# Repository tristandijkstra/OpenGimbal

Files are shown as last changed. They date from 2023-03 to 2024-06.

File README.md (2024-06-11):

# OpenGimbal

If you do end up using the platform for research then you can cite us using the details below:

@ARTICLE{10225720, author={Sharma, Suryansh and Dijkstra, Tristan and Prasad, Ranga Venkatesha}, journal={IEEE Sensors Letters}, title={Open Gimbal: A 3 Degrees of Freedom Open Source Sensing and Testing Platform for Nano- and Micro-UAVs}, year={2023}, volume={7}, number={9}, pages={1-4}, doi={10.1109/LSENS.2023.3307121}}



OpenGimbal is a specially designed 3 DoF test bench that caters to the unique requirements of mUAVs and nUAVs. This test bench allows for unrestricted rotational motion, enabling comprehensive experimentation and evaluation of these UAVs. Our approach focuses on simplicity and accessibility. We developed an open-source, 3D printable electro-mechanical  design that emphasizes minimal size and complexity. This design facilitates easy replication and customization, making it widely accessible to researchers and developers.

The CAD design files are available in both .step and .fbz. The Prusa slicer project used to print all components on a Prusa MK3S at once is also included. The design has been tested with a Crazyflie 2.1 and is intended to be attached to a standard tripod screw or kept on a table top with a suitable base.

For assembly of the tripod version, please refer to this [interactive model](https://teamtumbleweed3.autodesk360.com/g/shares/SH35dfcQT936092f0e431fe7335b7a1c18c6).
Further we also have a browser based version: [onshape link](https://cad.onshape.com/documents/f2281a1593cecd1e86d04a9a/w/4fd3c36d2f4a6c3e1b4013a5/e/7b1d20f3bce717410d81325e)

### Parts

| Component | Usage | Qty |
|---|---|-----|
| Ball Bearing Inner d = 3 \| Outer d = 9 \| Thickness = 5  | Inner 2 axes | 4 |
| Ball Bearing Inner d = 6 \| Outer d = 12 \| Thickness = 4 | Base | 2 |
| | | |
| M3 x 0.5 spacer | Inner 2 axes | 4 |
| DIN 912 M3 x 30mm halfthreaded screw | middle axis | 4 |
| DIN 912 M3 x 20mm halfthreaded screw | Inner axis | 2 |
| DIN 934 M3 hex nut | | 8 |
| | | |
| DIN 912 M2 x 12mm screw | Drone attachment | 2 |
| DIN 912 M2  hex nut | Drone attachment | 2 |
| | | |
| DIN 912 M6 x 30 mm halfthreaded screw | Base Connector | 1 |
| DIN 934 M6 hex nut | Base Connector | 1 |
| | | |
| m2 Threaded insets | Drone attachment | 2 |

### Gallery
#### Tripod Version
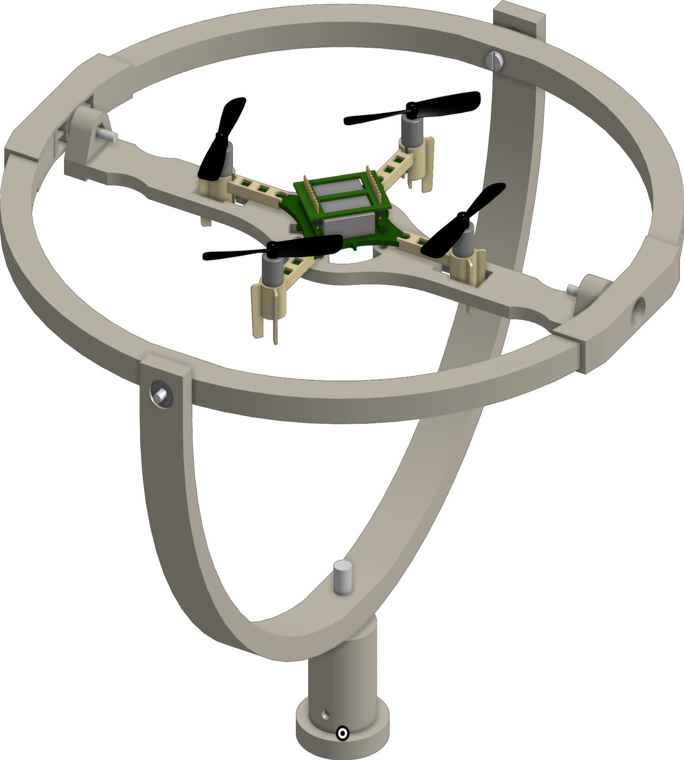
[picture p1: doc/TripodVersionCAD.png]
Tripod Version


#### Tabletop Version
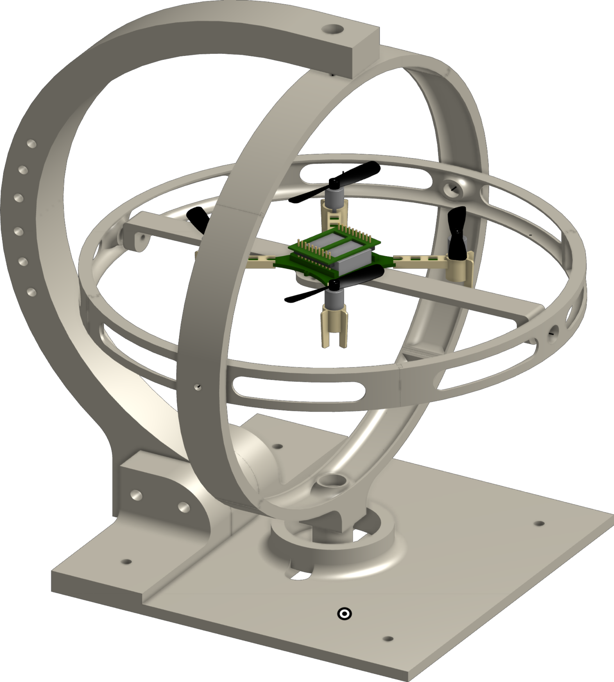
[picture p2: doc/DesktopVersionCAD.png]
Tabletop Version


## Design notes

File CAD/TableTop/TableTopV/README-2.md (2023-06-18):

Deafult version uses parts in main TableTopV directory and in(TableTopV/big_bearing_version). You can use standart bearing (8mm outer / 3 inner d) with base_8mm_bearing_version.

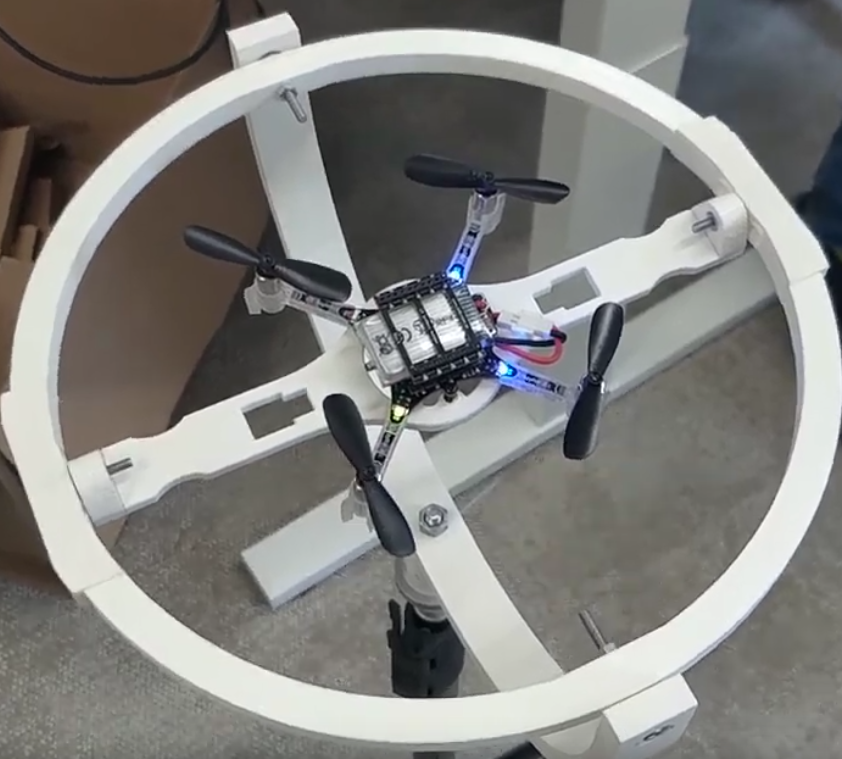
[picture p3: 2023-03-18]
doc/gimbal.png

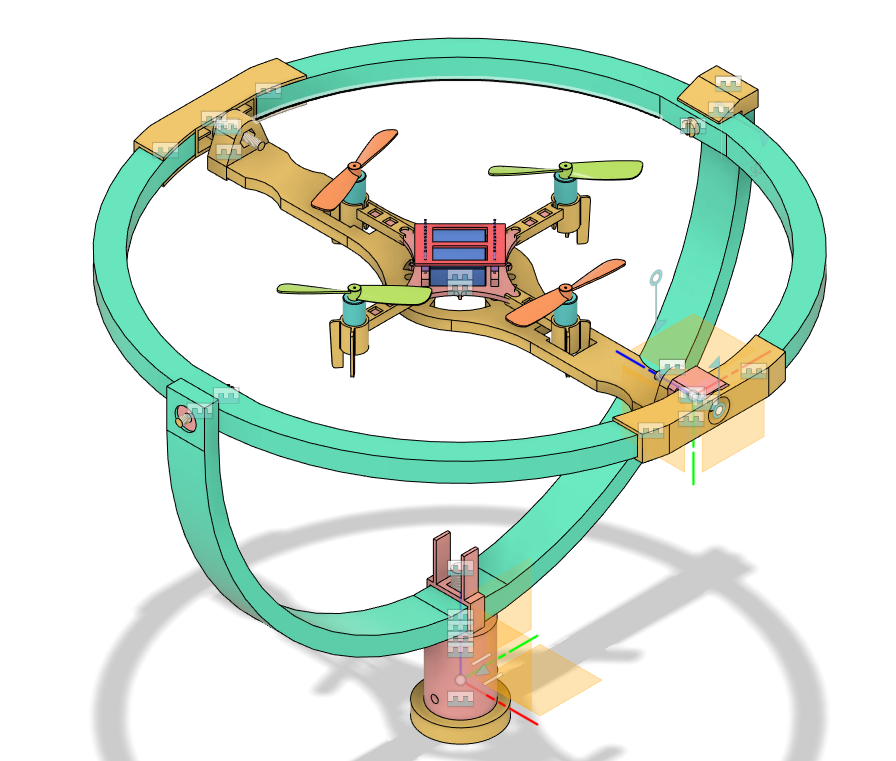
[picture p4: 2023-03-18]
doc/gimbalfusion.png

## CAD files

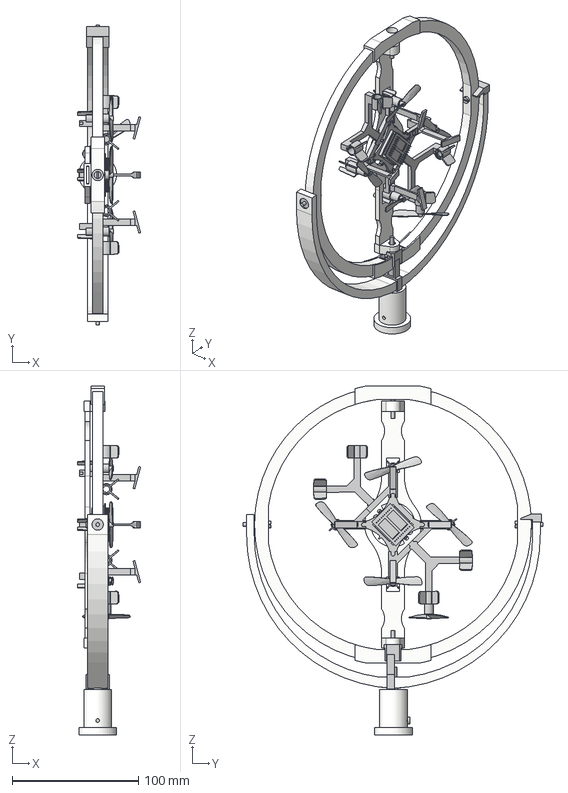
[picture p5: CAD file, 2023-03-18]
CAD/Tripod/assembly v45.step
50.3 x 237.9 x 276.9 mm
midRing x 2
midConnector x 2
inner connector V2 7mm base drone x 2
pcb
7mm motor mount x 4
7x15 motor x 4
propeller_ccw x 2
propeller_cw x 2
battery bc-bl-01-a
battery holder board
header x 2
inner V3
Motor_mount_blimp
3/9 mm bearing x 4
outer V3
Base core V2 thin
6 12 bearing x 2
din 912 m6
tripod attachement thin
M3 DIN934 x 2
20mm M3 slotted screw x 5
7x15 motor_1
propeller_cw_1
plate clip
top clip
bottom clip

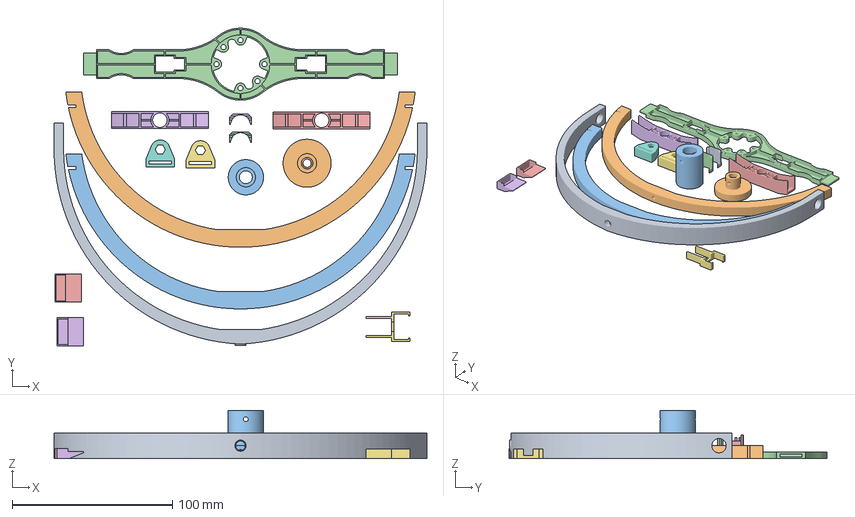
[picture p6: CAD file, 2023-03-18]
CAD/Tripod/prusaSlicerFullGimbal.3mf
233.0 x 198.4 x 30.0 mm
outer V3 v4.stl
midRing v13.stl x 2
inner V3 v24.stl
midConnector v8.stl x 2
inner connector V2 7mm base drone v7.stl x 2
plate clip v3.stl x 2
tripod attachement thin v2.stl
Base core V2 thin v2.stl
top clip v3.stl x 2
bottom clip v3.stl

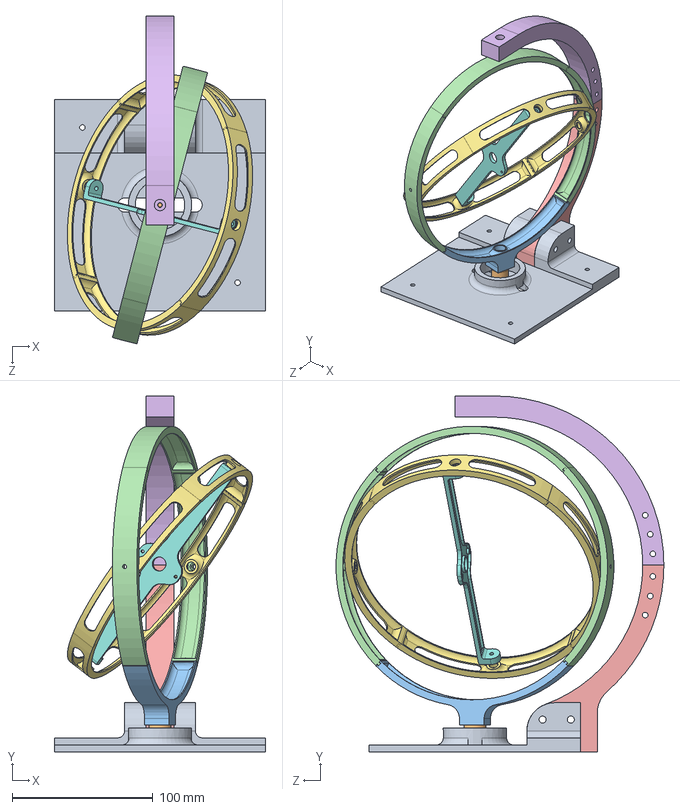
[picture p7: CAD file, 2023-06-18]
CAD/TableTop/TableTopV/assembly.SLDASM
150.0 x 252.5 x 232.5 mm
base_merged
pin
ring_2_foot
ring_2_quater_X3 x 3
vertical_support_part_bottom
vertical_support_part_top
ring_1_quater_X4 x 4
drone_mount_schell

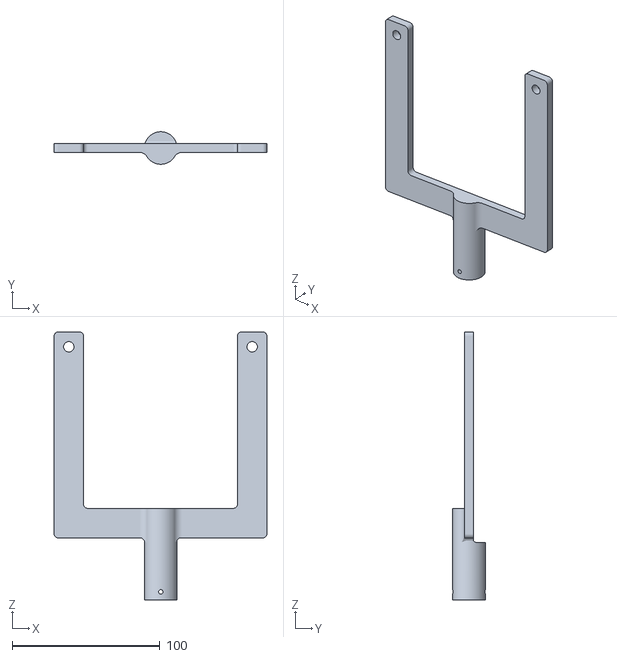
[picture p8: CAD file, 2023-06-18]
CAD/AntennaStand - AntennaBracket.stl
144.0 x 22.1 x 181.2

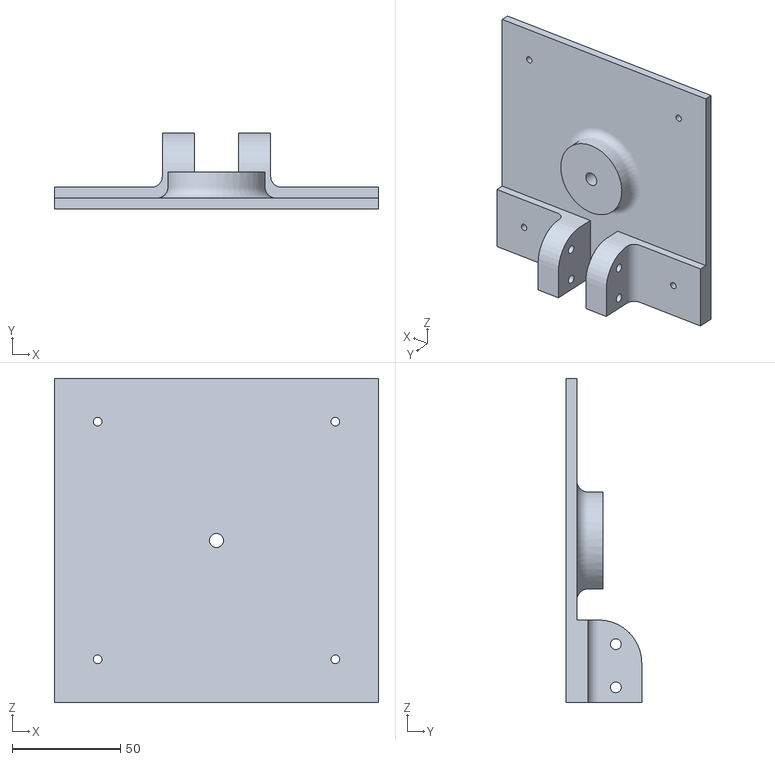
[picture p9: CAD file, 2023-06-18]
CAD/TableTop/STL/8mm_bearing/base_merged_8mm_bearing.STL
150.0 x 35.0 x 150.0

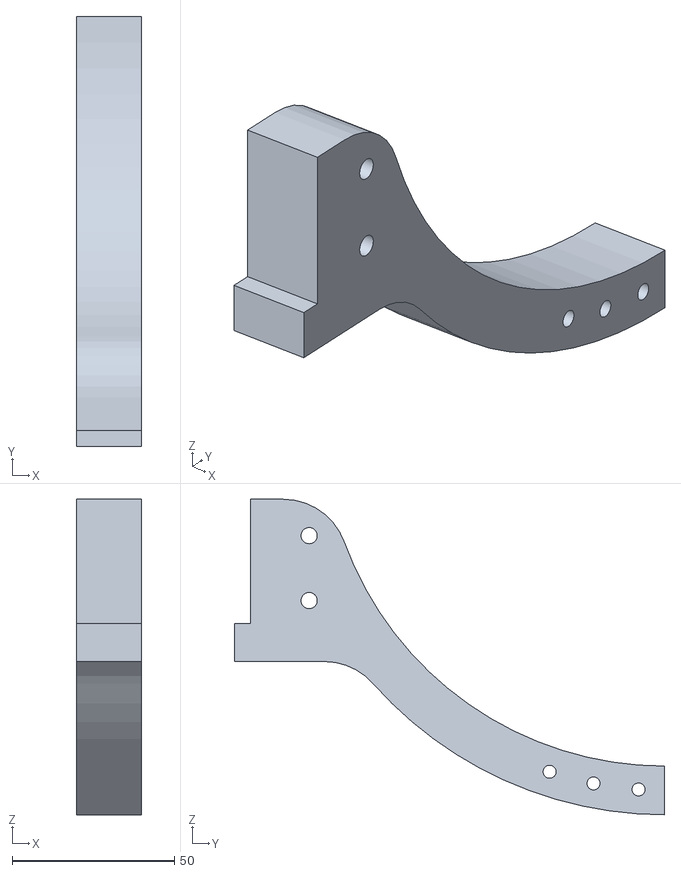
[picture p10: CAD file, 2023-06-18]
CAD/TableTop/STL/vertical_support_part_bottom.STL
20.0 x 132.5 x 97.2

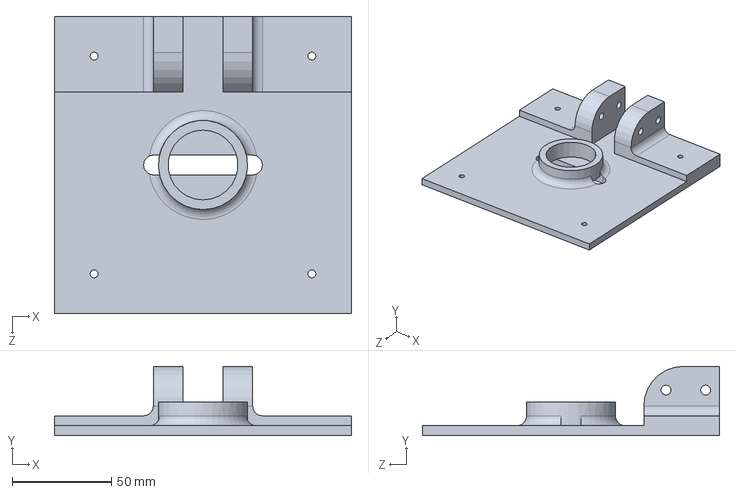
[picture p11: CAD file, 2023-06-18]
CAD/TableTop/TableTopV/base_8mm_bearing_version/base_merged.SLDPRT
150.0 x 35.0 x 150.0 mm

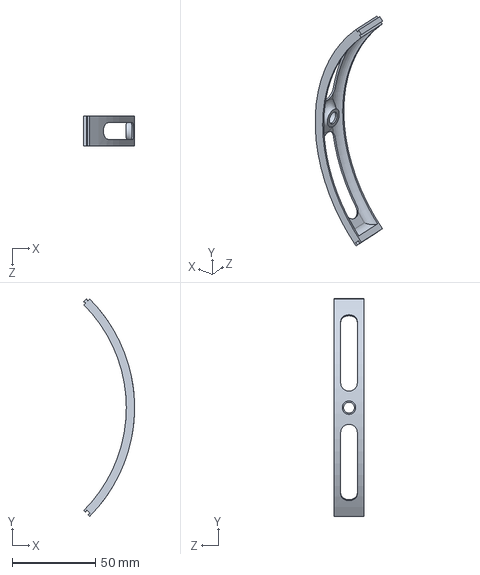
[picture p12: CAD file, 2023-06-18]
CAD/TableTop/TableTopV/ring_1_quater_X4.SLDPRT
30.8 x 131.0 x 18.0 mm

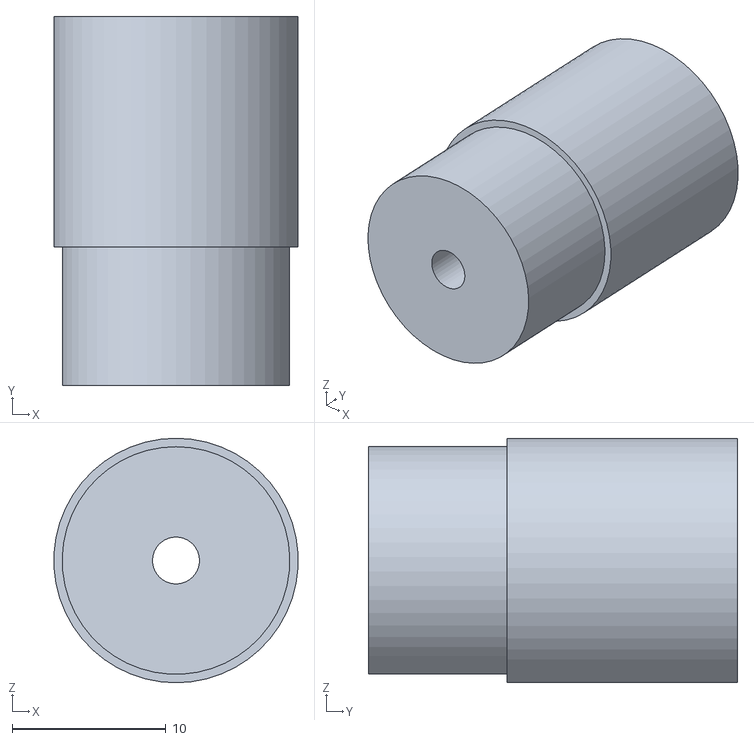
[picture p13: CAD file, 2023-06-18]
CAD/TableTop/STL/8mm_bearing/pin_bearing_8mm.STL
15.9 x 24.0 x 15.9

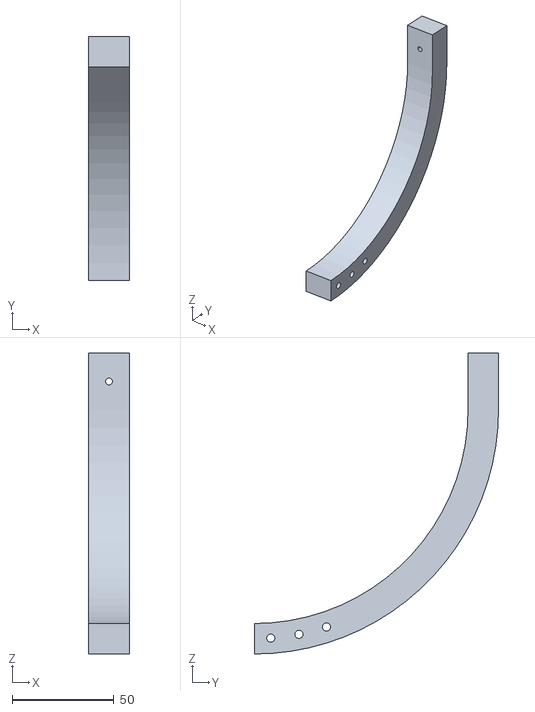
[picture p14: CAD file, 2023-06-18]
CAD/TableTop/STL/vertical_support_part_top.STL
20.0 x 120.0 x 148.0

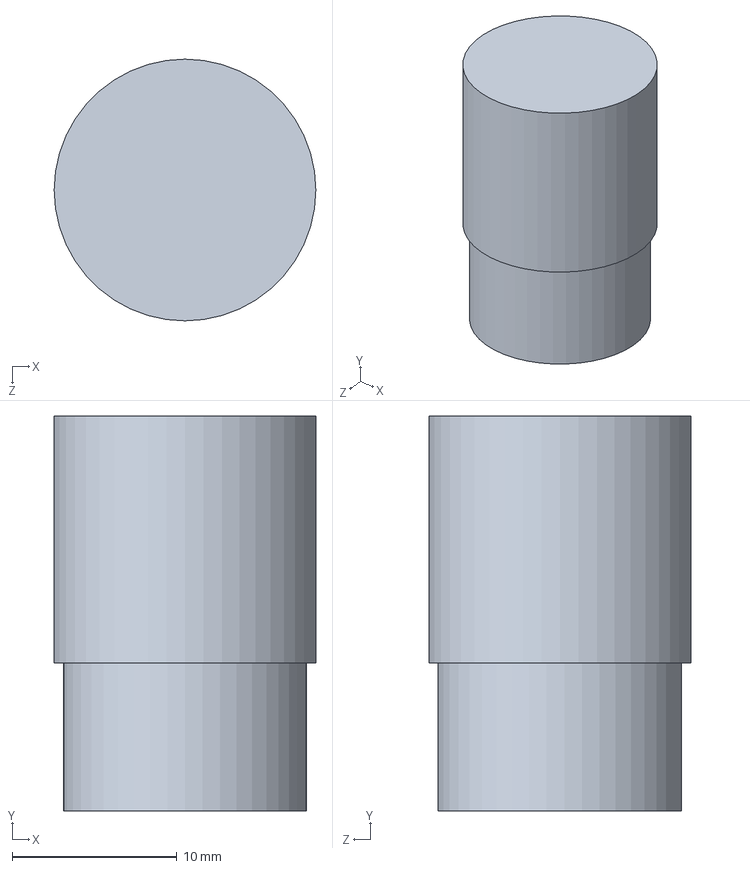
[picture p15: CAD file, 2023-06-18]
CAD/TableTop/TableTopV/big_bearing_version/pin.SLDPRT
15.9 x 24.0 x 15.9 mm

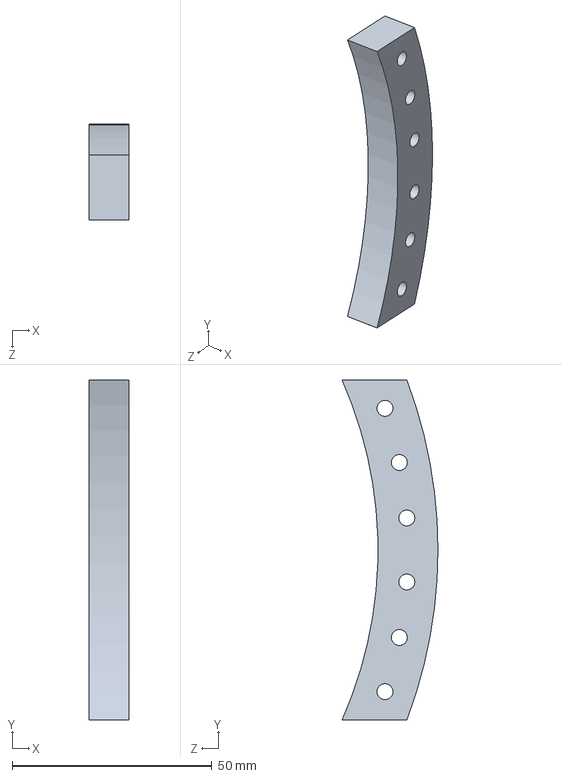
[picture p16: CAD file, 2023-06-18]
CAD/TableTop/TableTopV/clamp_X2.SLDPRT
10.0 x 85.0 x 24.0 mm

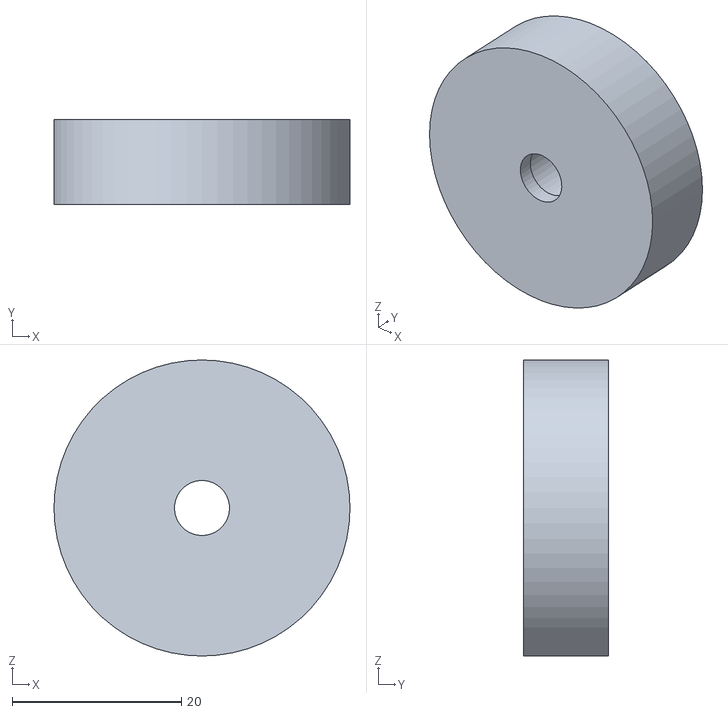
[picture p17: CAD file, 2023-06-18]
CAD/TableTop/STL/8mm_bearing/8mm_bearing_spacer.STL
35.0 x 10.00 x 35.0

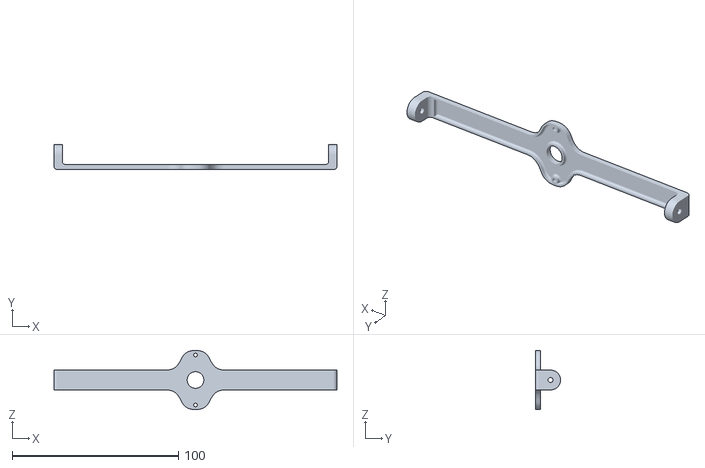
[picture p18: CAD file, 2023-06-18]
CAD/TableTop/STL/drone_mount_schell.STL
170.0 x 15.0 x 35.5

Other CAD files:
CAD/TableTop/TableTopV/base_8mm_bearing_version/base_merged_8mm_bearing.SLDPRT
CAD/TableTop/TableTopV/base_8mm_bearing_version/pin_bearing_8mm.SLDPRT
CAD/TableTop/TableTopV/ring_2_quater_X3.SLDPRT
CAD/TableTop/STL/base_merged.STL
CAD/TableTop/STL/clamp_X2.STL
CAD/TableTop/STL/pin.STL
CAD/TableTop/STL/ring_1_quater_X4.STL
CAD/TableTop/STL/ring_2_foot.STL
CAD/TableTop/STL/ring_2_quater_X3.STL
CAD/TableTop/TableTopV/base_8mm_bearing_version/8mm_bearing_spacer.SLDPRT
CAD/TableTop/TableTopV/base_8mm_bearing_version/base_merged_for_8mm_bearing_spacer.SLDPRT
CAD/TableTop/TableTopV/drone_mount_schell.SLDPRT
CAD/TableTop/TableTopV/ring_2_foot.SLDPRT
CAD/TableTop/TableTopV/vertical_support_part_bottom.SLDPRT
CAD/TableTop/TableTopV/vertical_support_part_top.SLDPRT
CAD/Tripod/assembly v45.f3z

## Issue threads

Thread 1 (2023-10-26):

location selling extra components

knmcguire, 2023-10-26:
Hi!

Could you perhaps share where you ordered the components from you need next to the 3d printed components? The ball bearings are of a size that is a bit difficult to find for our users (I'm assuming that the sizes indicated are in millimeters?)

https://github.com/tristandijkstra/OpenGimbal#parts

tristandijkstra, 2023-10-26:
Hi Kimberly,

The parts are all in milimeters yes. I ordered the originals from Conrad:

- https://www.conrad.nl/nl/p/reely-miniatuur-kogellager-chroomstaal-binnendiameter-3-mm-buitendiameter-9-mm-toerental-max-65000-omw-min-221985.html
- https://www.conrad.nl/nl/p/reely-rc-auto-kogellager-chroomstaal-binnendiameter-6-mm-buitendiameter-12-mm-toerental-max-43000-omw-min-295612.html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

I've seen similar sizes on RS as well:
- https://nl.rs-online.com/web/c/bearings-seals/rotary-bearings-housing-units/ball-bearings/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,4294871505

Hopefully this helps?

knmcguire, 2023-10-27:
Ah, thanks, super helpful! I was getting a bit worried as digikey and Amazon didn't show many options, but I forgot about Conrad!

Closed 2023-12-14.

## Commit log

2023-03-18 Add models and slicer set up
    [assembly v45.f3z, assembly v45.step, prusaSlicerFullGimbal.3mf]
2023-06-18 Reorganize repo, Update readme
    [8mm_bearing_spacer.SLDPRT, 8mm_bearing_spacer.STL, AntennaStand - AntennaBracket.stl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]
